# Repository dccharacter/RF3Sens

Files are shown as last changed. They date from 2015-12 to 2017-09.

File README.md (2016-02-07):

<pre>
//###########################################################################################
// RF3Sens (RoboForum triangulation range sensor)
// http://roboforum.ru/forum107/topic15929.html (official language for this forum - russian)
// MIT License
// 2015-2016
// Дмитрий Лилик (aka Dmitry__ @ RoboForum.ru)
// Андрей Пожогин (aka dccharacter  @ RoboForum.ru)
// Сергей Тараненко (aka setar @ RoboForum.ru)
//###########################################################################################
</pre>

Высокоточный (0.01+ mm) оптический барьерный датчик расстояния до поверхности стола 3D принтеров.
Основан на анализе картины засветки пзс матрицы (от мыши) рассеяным излучением от лазерного источника,
по принципу треугольника, при заранее известных углах установки лазера и матрицы.
Не зависит от типа материала стола (теоретически, методика пока в разработке).

Заявленная точность уже получена практическим путем на прототипах.
<pre>
vvv======== печатная каретка 3D принтера ==============vvv
  -- сенсор ------- лазер --(печатная плата сенсора)
         \\\\       ||||
            \         |
             \        |
              \       |
               \      |
                \     |
                 \    |
                  \   |
                   \  |
                    \ |
                     \|
------ уровень -------*--- срабатывания -------------------
                      |\
                      | \
    тут датчик не видит пятна лазера и нет срабатывания
^^^=============== стол 3D принтера ====================^^^
</pre>

* Схемы подключения разных ардуин (и других микроконтроллеров) в папке doc

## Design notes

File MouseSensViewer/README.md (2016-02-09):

Просмотрщик данных с пзс матриц мышек и визуализация картинки на комьютере.
Для:
RoboForum triangulation range sensor
http://roboforum.ru/forum107/topic15929.html (official language for this forum - russian)

##Сборка под Linux

'''
mkdir /home/user-name/tmp/MouseViewer
cd  /home/user-name/tmp/MouseViewer
qmake /path/to/RF3Sens/MouseSensViewer/Viewer.pro
make
'''

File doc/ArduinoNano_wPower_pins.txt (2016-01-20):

режим питания сенсора и лазера с ног микроконтроллера (подаем питание на нужные ноги)

--- сенсор ADNS-2610 --- 
OSC_IN (1 pin)        : на кварц 24MHz
OSC_OUT (2 pin)       : на кварц 24MHz
MOSI(3 pin)           : PB5 D13
SCK (4 pin)           : PB2 D10
GND (6 pin)           : PB4 D12
VDD (7 pin)           : PB3 D11
REFA (8 pin)          : через конденсатор 2.2МКФ на землю (6 pin)

--- лазерный диод 5mW ---
Laser VCC             : PD2 D2
Laser GND             : через сопротивление 100Ом на землю 

--- выход ---
MCU POWER (sensor +5V): VCC
MCU GND (sensor GND)  : GND
led (sensor signal)   : PC5 A5

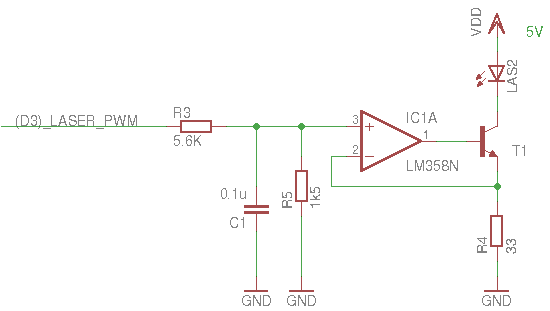
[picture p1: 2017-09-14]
doc/OpAmp-const-current-source.png

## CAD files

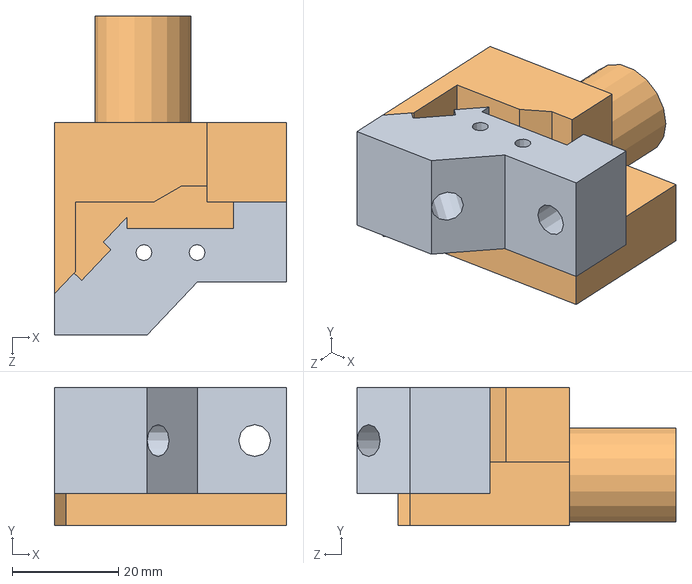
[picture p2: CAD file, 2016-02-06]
Models/universal_to_tube18mm.SLDASM
43.7 x 26.0 x 60.0 mm
Digispark_universal
universal_to_tube18mm

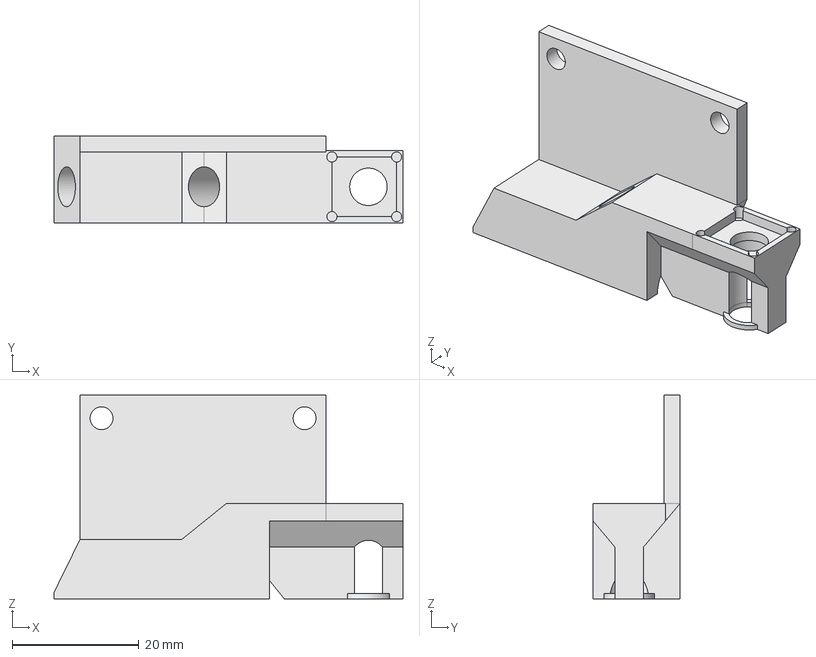
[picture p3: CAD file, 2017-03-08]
Models/Double_laser.FCStd
55.0 x 13.7 x 32.1 mm

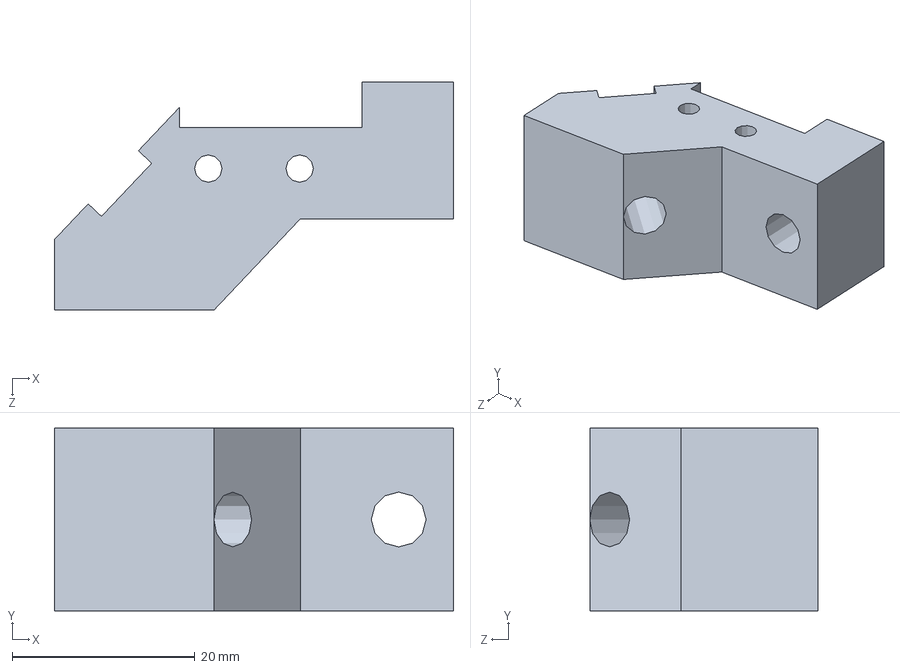
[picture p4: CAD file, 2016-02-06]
Models/Digispark_universal.SLDPRT
43.7 x 20.0 x 25.0 mm

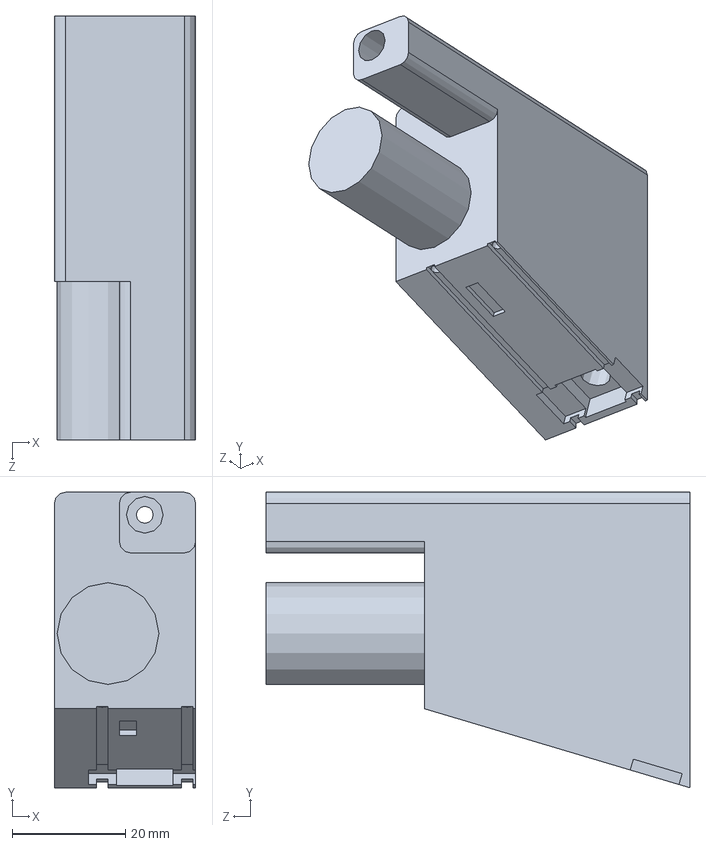
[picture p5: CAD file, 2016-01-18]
Models/ArduinoNano_wPower_tube18mm.SLDPRT
25.0 x 52.3 x 75.0 mm

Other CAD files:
Models/ArduinoNano_wPower_tube18mm.STL
Models/Double_laser.stl
Models/universal_to_tube18mm.SLDPRT
Models/universal_to_tube18mm.STL

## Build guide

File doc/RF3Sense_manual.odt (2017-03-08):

Синхронизация с электроникой принтера через g-code (trigger pin)

ссылка: http://roboforum.ru/post343825.html?hilit=trigger#p343825

G1 F2000 Z5 ;travel to initial position (absolute) <- здесь z устанавливаешь равным полному ходу датчика
G4 S1 ;sleep for 1 sec
M42 P4 S255 ;set trigger pin 4 HIGH (servo 4 signal pin)
G1 F60 Z0 ;travel to end position slowly
M400 ;wait for previous command to complete
M42 P4 S0 ;set trigger pin LOW

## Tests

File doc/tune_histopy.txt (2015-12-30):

Sketch uses 1 268 bytes (4%) of program storage space. Maximum is 30 720 bytes.
Global variables use 236 bytes (11%) of dynamic memory, leaving 1 812 bytes for local variables. Maximum is 2 048 bytes.

программный spi
Sketch uses 912 bytes (2%) of program storage space. Maximum is 30 720 bytes.
Global variables use 235 bytes (11%) of dynamic memory, leaving 1 813 bytes for local variables. Maximum is 2 048 bytes.

SoftSerial
Sketch uses 3 012 bytes (50%) of program storage space. Maximum is 6 012 bytes.
Global variables use 129 bytes of dynamic memory.
замена SoftSerial на SendOnlySoftwareSerial
Sketch uses 1 878 bytes (31%) of program storage space. Maximum is 6 012 bytes.
Global variables use 42 bytes of dynamic memory.

Sketch uses 4 468 bytes (14%) of program storage space. Maximum is 30 720 bytes.
Global variables use 254 bytes (12%) of dynamic memory, leaving 1 794 bytes for local variables. Maximum is 2 048 bytes.
без Serial.println(String(Frame...
Sketch uses 2 866 bytes (9%) of program storage space. Maximum is 30 720 bytes.
Global variables use 247 bytes (12%) of dynamic memory, leaving 1 801 bytes for local variables. Maximum is 2 048 bytes.

Выпилил ненужный:
Frame[(ARRAY_WIDTH * ARRAY_HEIGHT)+1] = 0xff;  // frame data is 0..63 or 0..127 so delimiter 255 is safe

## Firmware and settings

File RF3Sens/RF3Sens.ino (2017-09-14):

//###########################################################################################
// RF3Sens (RoboForum triangulation range sensor)
// http://roboforum.ru/forum107/topic15929.html (official language for this forum - russian)
// MIT License
// 2015-2016
// Дмитрий Лилик (aka Dmitry__ @ RoboForum.ru)
// Андрей Пожогин (aka dccharacter  @ RoboForum.ru)
// Сергей Тараненко (aka setar @ RoboForum.ru)
//###########################################################################################

#include "Config.h"
#if defined(DEBUG_TYPE) && defined(SOFTWARE_SERIAL)
  #include <SendOnlySoftwareSerial.h>
#endif //#if defined(DEBUG_TYPE) && defined(SOFTWARE_SERIAL)

byte ADNS_read(uint8_t address);
void ADNS_reset(void);
void ADNS_write(uint8_t addr, uint8_t data);
inline void params_grab(uint8_t *buffer, uint8_t ifReset);
inline void pixel_grab(uint8_t *buffer, uint16_t nBytes); 
inline void pixel_and_params_grab(uint8_t *buffer);
inline uint8_t single_line_grab(uint8_t *buffer);
void RefrPowerLaser(uint16_t power, uint16_t value, uint16_t halfDev);
void ByteToString(uint8_t a);
void Uint16ToString(uint16_t a);

unsigned char Str[5];
int16_t RegPowLaser = 0;

void setup(){
  pinMode(3, OUTPUT);
  TCCR2A = 0;
  TCCR2B = 0;
  TCCR2A = _BV(COM2B1) | _BV(WGM21) | _BV(WGM20);
  TCCR2B = _BV(CS20); // no prescaler
  OCR2B = 50;

  pinMode(A5, INPUT);

  //set pin I/O direction
#if defined(USE_NCS)
  PIN_OUTPUT(NCS);
  PIN_HIGH(NCS);
#endif //USE_NCS
  PIN_OUTPUT(LED);
  PIN_HIGH(LED);
#if defined(DEBUG_TYPE) && defined(TRIG_PIN)
  PIN_INPUT(TRIG);
#endif //defined(DEBUG_TYPE) && defined(TRIG_PIN)


  PIN_OUTPUT(laser1_vcc);
  PIN_OUTPUT(laser2_vcc);
  PIN_OUTPUT(laser_pwm);
  analogWrite(9, 0); //preset all analogWrite values so I can just later change OCR1A

//initialize SPI
  PIN_OUTPUT(NCLOCK);
  PIN_HIGH(NCLOCK);
  PIN_OUTPUT(SDIO);
  PIN_LOW(SDIO);

//#if defined(DEBUG_TYPE)
  SERIAL_OUT.begin(SERIAL_SPEED);
//#endif // defined(DEBUG_TYPE)

  delay(1000);
  ADNS_reset();
}

void loop(){
//###########################################################################################
// штатный режим датчика для 3D принтера
#ifndef DEBUG_TYPE
  uint8_t Frame[NUM_PIXS + 7] = {0};
  uint8_t dataSum, dataSqual, lineMax;
  
  PIN_LOW(LED);

  PIN_LOW(laser1_vcc); //enable base laser
  analogWrite(9,130);

  while(1){
    params_grab(Frame, 1);
    dataSum = Frame[3];
    dataSqual = Frame[0];
    ByteToString(RegPowLaser); SERIAL_OUT.write(Str[2]); SERIAL_OUT.write(Str[1]);
      SERIAL_OUT.write(Str[0]); SERIAL_OUT.write(0x09);
    ByteToString(dataSum); SERIAL_OUT.write(Str[2]); SERIAL_OUT.write(Str[1]);
      SERIAL_OUT.write(Str[0]); SERIAL_OUT.write(0x09);
    if (dataSqual > 30) {
      lineMax = single_line_grab(Frame);
      ByteToString(lineMax); SERIAL_OUT.write('.'); SERIAL_OUT.write(Str[2]); SERIAL_OUT.write(Str[1]);
        SERIAL_OUT.write(Str[0]); SERIAL_OUT.write(0x0a);
      if (lineMax > 60) {
          PIN_HIGH(LED);
          delay(100);
      }
    }
    RefrPowerLaser(dataSum, 23, 2);
    SERIAL_OUT.write(0x0a);
    
    PIN_LOW(LED);
  }
//###########################################################################################
// отладочные режимы
#else //ifndef DEBUG_TYPE
//-------------------------------------------------------------------------------------------
#if DEBUG_TYPE ==1
//-------------------------------------------------------------------------------------------
  byte Frame[NUM_PIXS + 7] = {0}, dataMax, lineMax;
  byte dataMin, lineMin;
  //uint8_t laserId = 2; // 0 = off; 1 = laser 1; 2 = laser 2; 
  //uint16_t dataShutt;
  
  PIN_LOW(LED);

  PIN_LOW(laser1_vcc); //enable base laser
  PIN_HIGH(laser2_vcc); //disable matrix laser
  analogWrite(9,130);

  while(1){
    //pixel_and_params_grab(Frame);
    //dataMax = Frame[NUM_PIXS + 1];
    //lineMax = Frame[NUM_PIXS + 0];
    //lineMin = Frame[NUM_PIXS + 3];

    //RegPowLaser = (uint8_t)(analogRead(A5) >> 2);    
    //OCR2B = RegPowLaser;
    OCR2B += 1;
   //   }
     /* if (lineMax > 22) { //bingo!
        PIN_HIGH(LED);
        delay(200);
      } else {
        PIN_LOW(LED);
      }*/
    delay(1);
    //} else {
    //  PIN_LOW(LED);
    //}
    
    //SERIAL_OUT.write(Frame, NUM_PIXS + 7); delay(2);// send frame in raw format
  }
//-------------------------------------------------------------------------------------------
#elif DEBUG_TYPE ==2
//-------------------------------------------------------------------------------------------
  byte Frame[NUM_PIXS + 7];

  byte data;
  while(1){
    //data = ADNS_read(ADNS_SQUAL);
    data = ADNS_read(ADNS_MAX_PIX);
    //data = ADNS_read(ADNS_PIX_SUM);

    if(data > ADNS_CONST_MAX){
      PIN_LOW(LED);
    }
    else{
      PIN_HIGH(LED);
      pixel_and_params_grab(Frame);
      SERIAL_OUT.write(Frame, NUM_PIXS+7); // send frame in raw format
    }
  }
//-------------------------------------------------------------------------------------------
#elif DEBUG_TYPE ==3
//-------------------------------------------------------------------------------------------
  //листинг для электронных таблиц: В шапке названия, дальше только данные разделенные "tab".
  byte Frame[7];
  uint8_t dataMax, lineMax, dataSum;
  //заголовок
  SERIAL_OUT.println  (F  ("Squal:\tMax:\tMin:\tSum:\tShutter:\tLaserPower:"));
  while(1){
//        RegPowLaser = OCR2B;    
//	OCR2B += 1;
//    params_grab(Frame);

    single_line_grab(Frame);
    dataMax = Frame[NUM_PIXS + 1];
    //dataMin = Frame[NUM_PIXS + 2];
    lineMax = Frame[NUM_PIXS + 0];
    dataSum = Frame[NUM_PIXS + 3];

    //if (dataMax - dataMin > 30) { //laser spot is visible, arm the sensor
    //  if (!(dataMax - dataMin > 40 && lineMax - lineMin > 7)) { //spot has not reached the last line
        //dataShutt = ((*(Frame + NUM_PIXS + 4)) << 8) + *(Frame + NUM_PIXS + 5);
    RefrPowerLaser(dataSum, 35, 2);
    //   }
    if (lineMax > 60) { //22 - bingo!
      PIN_HIGH(LED);
      delay(100);
    } else {
      PIN_LOW(LED);
}
    ByteToString(Frame[NUM_PIXS + 0]); SERIAL_OUT.write(Str[2]); SERIAL_OUT.write(Str[1]); SERIAL_OUT.write(Str[0]); SERIAL_OUT.write(0x09);
    ByteToString(Frame[NUM_PIXS + 1]); SERIAL_OUT.write(Str[2]); SERIAL_OUT.write(Str[1]); SERIAL_OUT.write(Str[0]); SERIAL_OUT.write(0x09);
    //ByteToString(Frame[2]); SERIAL_OUT.write(Str[2]); SERIAL_OUT.write(Str[1]); SERIAL_OUT.write(Str[0]); SERIAL_OUT.write(0x09);
    ByteToString(Frame[NUM_PIXS + 3]); SERIAL_OUT.write(Str[2]); SERIAL_OUT.write(Str[1]); SERIAL_OUT.write(Str[0]); SERIAL_OUT.write(0x09);
    Uint16ToString(Frame[NUM_PIXS + 4] *256 + Frame[NUM_PIXS + 5]);
    SERIAL_OUT.write(Str[4]);
    SERIAL_OUT.write(Str[3]);
    SERIAL_OUT.write(Str[2]);
    SERIAL_OUT.write(Str[1]);
    SERIAL_OUT.write(Str[0]);
    SERIAL_OUT.write(0x09);
    ByteToString(Frame[NUM_PIXS + 6]); SERIAL_OUT.write(Str[2]); SERIAL_OUT.write(Str[1]); SERIAL_OUT.write(Str[0]); SERIAL_OUT.write(0x09);
    SERIAL_OUT.write(0x0d);
    SERIAL_OUT.write(0x0a);

#if SERIAL_SPEED > 115200
      delay(20);
#else
      delay(60);  //задержка больше из-за низкой скорости Serial
#endif
  }
//-------------------------------------------------------------------------------------------
#elif DEBUG_TYPE ==4
//-------------------------------------------------------------------------------------------
  //Как 3-й режим, но по разрешению сигнала pin_TRIG
  byte Frame[7];
  PIN_OUTPUT(gpio1);
  PIN_LOW(gpio1);

  PIN_LOW(laser1_vcc); //enable base laser
  PIN_HIGH(laser2_vcc); //disable matrix laser
  RegPowLaser = 140;
  analogWrite(9, RegPowLaser);

  // начинаем с печати шапки
  SERIAL_OUT.println (F  ("Squal:\tMax:\tMin:\tSum:\tShutter:\tLaserPower:"));

  while(1){

    if(PIN_READ(TRIG)){ // каждое измерение начинается с сигнала триггера (взводится в g-коде)
      
      while(PIN_READ(TRIG));

      params_grab(Frame);

      ByteToString(Frame[0]); SERIAL_OUT.write(Str[2]); SERIAL_OUT.write(Str[1]); SERIAL_OUT.write(Str[0]); SERIAL_OUT.write(0x09);
      ByteToString(Frame[1]); SERIAL_OUT.write(Str[2]); SERIAL_OUT.write(Str[1]); SERIAL_OUT.write(Str[0]); SERIAL_OUT.write(0x09);
      ByteToString(Frame[2]); SERIAL_OUT.write(Str[2]); SERIAL_OUT.write(Str[1]); SERIAL_OUT.write(Str[0]); SERIAL_OUT.write(0x09);
      ByteToString(Frame[3]); SERIAL_OUT.write(Str[2]); SERIAL_OUT.write(Str[1]); SERIAL_OUT.write(Str[0]); SERIAL_OUT.write(0x09);
      Uint16ToString(Frame[4] *256 + Frame[5]);
      SERIAL_OUT.write(Str[4]);
      SERIAL_OUT.write(Str[3]);
      SERIAL_OUT.write(Str[2]);
      SERIAL_OUT.write(Str[1]);
      SERIAL_OUT.write(Str[0]);
      SERIAL_OUT.write(0x09);
      ByteToString(Frame[6]); SERIAL_OUT.write(Str[2]); SERIAL_OUT.write(Str[1]); SERIAL_OUT.write(Str[0]); SERIAL_OUT.write(0x09);
      SERIAL_OUT.write(0x0a);
      SERIAL_OUT.write(0x0d);

#if SERIAL_SPEED > 115200
      delay(20);
#else
      delay(60);  //задержка больше из-за низкой скорости Serial
#endif

    // после того, как считали значения и отправили их в сериал, даем марлину
    // сигнал о готовности к следующему шагу
    PIN_HIGH(gpio1);
    delay(40);
    PIN_LOW(gpio1);
    }
  }
//-------------------------------------------------------------------------------------------
#elif DEBUG_TYPE ==5
//-------------------------------------------------------------------------------------------
  while(1){
    unsigned int motion = 0;
    //check for movement
    motion = ADNS_read(ADNS_MOTION);
    if (motion > 127){
      //there has been a motion! Print the x and y movements
      SERIAL_OUT.println("X:" + String(ADNS_read(ADNS_DELTA_X)) + " Y:" + String(ADNS_read(ADNS_DELTA_Y)));
    }
  }
//-------------------------------------------------------------------------------------------
#elif DEBUG_TYPE ==6
//-------------------------------------------------------------------------------------------
  uint8_t Frame[7];
  uint8_t laserId = 2; // 0 = off; 1 = laser 1; 2 = laser 2; 
  //заголовок

  SERIAL_OUT.println  (F  ("Squal:\tMax:\tMin:\tSum:\tShutter:\tLaserId:"));
  while(1){
    params_grab(Frame);

  if (laserId == 2) {
	  PIN_HIGH(laser1_vcc);
	  PIN_LOW(laser2_vcc);
	  laserId = 1;
  } else {
	  PIN_HIGH(laser2_vcc);
	  PIN_LOW(laser1_vcc);
	  laserId = 2;
  }
    ByteToString(Frame[0]); SERIAL_OUT.write(Str[2]); SERIAL_OUT.write(Str[1]); SERIAL_OUT.write(Str[0]); SERIAL_OUT.write(0x09);
    ByteToString(Frame[1]); SERIAL_OUT.write(Str[2]); SERIAL_OUT.write(Str[1]); SERIAL_OUT.write(Str[0]); SERIAL_OUT.write(0x09);
    ByteToString(Frame[2]); SERIAL_OUT.write(Str[2]); SERIAL_OUT.write(Str[1]); SERIAL_OUT.write(Str[0]); SERIAL_OUT.write(0x09);
    ByteToString(Frame[3]); SERIAL_OUT.write(Str[2]); SERIAL_OUT.write(Str[1]); SERIAL_OUT.write(Str[0]); SERIAL_OUT.write(0x09);
    Uint16ToString(Frame[4] *256 + Frame[5]);
    SERIAL_OUT.write(Str[4]);
    SERIAL_OUT.write(Str[3]);
    SERIAL_OUT.write(Str[2]);
    SERIAL_OUT.write(Str[1]);
    SERIAL_OUT.write(Str[0]);
    SERIAL_OUT.write(0x09);
    ByteToString(laserId); SERIAL_OUT.write(Str[2]); SERIAL_OUT.write(Str[1]); SERIAL_OUT.write(Str[0]); SERIAL_OUT.write(0x09);
    SERIAL_OUT.write(0x0d);
    SERIAL_OUT.write(0x0a);

#if SERIAL_SPEED > 115200
      delay(20);
#else
      delay(60);  //задержка больше из-за низкой скорости Serial
#endif //SERIAL_SPEED > 115200
  }
#endif //DEBUG_TYPE
#endif // #else #ifndef DEBUG_TYPE
}

//###########################################################################################
// процедуры
//-------------------------------------------------------------------------------------------
void RefrPowerLaser(uint16_t power, uint16_t target_value, uint16_t halfDeviation)
{
  //if (abs((int16_t)target_value - (int16_t)power) > halfDeviation) {
    if (power < target_value) {
      RegPowLaser++;
    } else if (power > target_value) {
      RegPowLaser--;
    }
    if (RegPowLaser > 255) {
      RegPowLaser = 255;
    } else if (RegPowLaser < 0) {
      RegPowLaser = 0;
    }
    OCR2B = (uint8_t)RegPowLaser;
  //}
}
//-------------------------------------------------------------------------------------------
void ADNS_reset(void){
#ifdef sens_type_ADNS_5020
  ADNS_write(0x3a,0x5a);
  delay(1000);
  ADNS_write(0x0d, 0x01);  // Set 1000cpi resolution
  delay(1000);
#endif
#if  defined(sens_type_ADNS_2610) || defined(sens_type_ADNS_2620)
  ADNS_write(ADNS_CONF,0x80);
  delay(1000);
  ADNS_write(ADNS_CONF,0x01); //Always awake
  delay(2);
  ADNS_write(ADNS_FRAME_PERIOD, 0xC2); //set framerate to 3000fps
  delay(2);
#endif
}

//-------------------------------------------------------------------------------------------
void ADNS_write(byte address, byte data){
  #if defined(USE_NCS)
    PIN_LOW(NCS);
  #endif
  // send in the address and value via SPI:
  address |= 0x80;  //признак записи адреса
  for (byte i = 0x80; i; i >>= 1){
    PIN_LOW(NCLOCK);
    address & i ? PIN_HIGH(SDIO) : PIN_LOW(SDIO);
    asm volatile ("nop");
    PIN_HIGH(NCLOCK);
  }

  //delayMicroseconds(1);

  for (byte i = 0x80; i; i >>= 1){
    PIN_LOW(NCLOCK);
    data & i ? PIN_HIGH(SDIO) : PIN_LOW(SDIO);
    asm volatile ("nop");
    PIN_HIGH(NCLOCK);
  }
  //t SWW. SPI Time between Write Commands
  delayMicroseconds(ADNS_DELAY_TSWW);

  #if defined(USE_NCS)
    PIN_HIGH(NCS);
  #endif
}

//-------------------------------------------------------------------------------------------
byte ADNS_read(byte address){
  #if defined(USE_NCS)
    PIN_LOW(NCS);
  #endif

  address &= ~0x80;  //признак записи данных
  for (byte i = 0x80; i; i >>= 1){
    PIN_LOW(NCLOCK);
    address & i ? PIN_HIGH(SDIO) : PIN_LOW(SDIO);
    asm volatile ("nop");
    PIN_HIGH(NCLOCK);
  }

  // prepare io pin for reading
  PIN_INPUT(SDIO);

  // t SRAD. SPI Read Address-Data Delay
  delayMicroseconds(ADNS_DELAY_TSRAD);

  // read the data
  byte data = 0;
  for (byte i = 8; i; i--){
    // tick, tock, read
    PIN_LOW(NCLOCK);
    asm volatile ("nop");
    PIN_HIGH(NCLOCK);
    data <<= 1;
    if (PIN_READ(SDIO)) data |= 0x01;
  }

  #if defined(USE_NCS)
    PIN_HIGH(NCS);
  #endif
  PIN_OUTPUT(SDIO);
  // t SRW & t SRR = 1μs.
  delayMicroseconds(2);
  return data;
}
//-------------------------------------------------------------------------------------------
inline uint8_t single_line_grab(uint8_t *buffer) {

  uint8_t temp_byte;
  //uint16_t nBytes = NUM_PIXS; //18;
  uint16_t nBytes = 18;
  uint8_t linePix = 18;
  uint8_t lineMax = 0;
  //uint8_t lineMin = 255; //determine max and min pix in data read

  //reset the pixel grab counter
  ADNS_write(ADNS_PIX_GRAB, 0x00);

  for (uint16_t count = 0; count < nBytes; count++) {
    while (1) {
      temp_byte = ADNS_read(ADNS_PIX_GRAB);
      if (temp_byte & ADNS_PIX_DATA_VALID) {
        break;
      }
    }
    temp_byte &= ADNS_MASK_PIX;
    *(buffer + count) = temp_byte;  // only n bits are used for data
    if (temp_byte > lineMax) {
      lineMax = temp_byte;
    }
    //if (temp_byte < lineMin) {
    //  lineMin = temp_byte;
    //}
  }

  return lineMax;
}
//-------------------------------------------------------------------------------------------
inline void pixel_grab(uint8_t *buffer, uint16_t nBytes) {
  uint8_t temp_byte;

  //reset the pixel grab counter
  ADNS_write(ADNS_PIX_GRAB, 0x00);

  for (uint16_t count = 0; count < nBytes; count++) {
    while (1) {
      temp_byte = ADNS_read(ADNS_PIX_GRAB);
      if (temp_byte & ADNS_PIX_DATA_VALID) {
        break;
      }
    }
    *(buffer + count) = temp_byte & ADNS_MASK_PIX;  // only n bits are used for data
  }
}
//-------------------------------------------------------------------------------------------
inline void params_grab(uint8_t *buffer, uint8_t ifReset) {
  if (ifReset) {
    uint8_t temp_byte;
    ADNS_write(ADNS_PIX_GRAB, 0x00);
    while (1) {
      temp_byte = ADNS_read(ADNS_PIX_GRAB);
      if (temp_byte & ADNS_PIX_DATA_VALID) {
        break;
      }
    }
  }
  *(buffer + 0) = ADNS_read(ADNS_SQUAL);
  *(buffer + 1) = ADNS_read(ADNS_MAX_PIX);
  *(buffer + 2) = ADNS_read(ADNS_MIN_PIX);
  *(buffer + 3) = ADNS_read(ADNS_PIX_SUM);
  *(buffer + 4) = ADNS_read(ADNS_SHUTTER_UPPER);
  *(buffer + 5) = ADNS_read(ADNS_SHUTTER_LOWER);
  *(buffer + 6) = (uint8_t)RegPowLaser;
}
//-------------------------------------------------------------------------------------------
inline void pixel_and_params_grab(uint8_t *buffer) {
	pixel_grab(buffer, NUM_PIXS);
	params_grab(buffer + NUM_PIXS, 0);
}
//-------------------------------------------------------------------------------------------
void ByteToString(uint8_t a){
  Str[0] = '0';
  Str[1] = '0';
  Str[2] = '0';
  if (!a) return;
  Str[0] = a % 10 + '0'; a /= 10;
  if (!a) return;
  Str[1] = a % 10 + '0'; a /= 10;
  if (!a) return;
  Str[2] = a % 10 + '0';
}
//-------------------------------------------------------------------------------------------
void Uint16ToString(uint16_t a){
  Str[0] = '0';
  Str[1] = '0';
  Str[2] = '0';
  Str[3] = '0';
  Str[4] = '0';
  if (!a) return;
  Str[0] = a % 10 + '0'; a /= 10;
  if (!a) return;
  Str[1] = a % 10 + '0'; a /= 10;
  if (!a) return;
  Str[2] = a % 10 + '0'; a /= 10;
  if (!a) return;
  Str[3] = a % 10 + '0'; a /= 10;
  if (!a) return;
  Str[4] = a % 10 + '0';
}
//-------------------------------------------------------------------------------------------
uint8_t ByteToAscii_h(uint8_t x){
  uint8_t tmpByte;

  tmpByte = (x >> 4) + 0x30;
  if (tmpByte > 0x39) { tmpByte += 0x07; }
  return tmpByte;
}
//-------------------------------------------------------------------------------------------
uint8_t ByteToAscii_l(uint8_t x){
  uint8_t tmpByte;
  tmpByte = (x & 0x0f) + 0x30;
  if (tmpByte > 0x39) { tmpByte += 0x07; }
  return tmpByte;
}

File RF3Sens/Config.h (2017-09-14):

//###########################################################################################
// RF3Sens (RoboForum triangulation range sensor)
// http://roboforum.ru/forum107/topic15929.html (official language for this forum - russian)
// MIT License
// 2015-2016
// Дмитрий Лилик (aka Dmitry__ @ RoboForum.ru)
// Андрей Пожогин (aka dccharacter  @ RoboForum.ru)
// Сергей Тараненко (aka setar @ RoboForum.ru)
//###########################################################################################

/* Config.h */
//###########################################################################################
//        Ручные настройки
//###########################################################################################
/*
При отсутствии флага DEBUG_TYPE, программа быстро обрабатывает соотв. регистр и выдает данные на led (штатная работа принтера).
При установленном флаге DEBUG_TYPE, по serial port передаются данные:
DEBUG_TYPE = 1  Передача картинки для фокусировки обьектива, колич. байт = ARRAY_WIDTH * ARRAY_HEIGHT
DEBUG_TYPE = 2  Для теста точности позиционирования (идея dccharacter-а). 
                Поиск порога как в штатном режиме (важна скорость), как только сработает порог - выдача картинки в serial port
DEBUG_TYPE = 3  Передача в текстовом виде на терминал данных: Max_Pix, Min_Pix, Pix_Sum, Shutter
DEBUG_TYPE = 4  Как 3-й режим, но по разрешению сигнала pin_TRIG (лог точно ограничен сигналом z_probe)
DEBUG_TYPE = 5  Данные перемещения мышки.
DEBUG_TYPE = 6 Тестирование режима двойного лазера
*/
#define DEBUG_TYPE 1 
#define NUM_SAMPLES_PER_MEASURE 5 //количество данных для 4-го режима

/*
Актуально только если есть флаг DEBUG_TYPE
Если определено то применяется программный Serial порт (только одна нога для передачи данных)
Для платы Digispark это единственный вариант и автоматически включается на 1 ногу
Если не определено, для дебага используется Hardware Serial
*/
//#define SOFTWARE_SERIAL 1 // одновременно и признак софтового serial и номер ноги для передачи данных (TX PIN)
#define SERIAL_SPEED 230400

/*
Тип сенсора, выбрать один нужный
*/
//#define SENS_TYPE_ADNS_5020
//#define SENS_TYPE_ADNS_2610
#define SENS_TYPE_ADNS_2620

/*
Используем ли питание с контроллера
*/
//#define laser_power_via_mcu // режим питания лазера с ног микроконтроллера (подаем питание на нужные ноги)
//#define sens_power_via_mcu // режим питания сенсора с ног микроконтроллера (подаем питание на нужные ноги)

/*
Тип контроллера, выбрать один нужный
*/
//#define DIGI_SPARK
//#define ARDUINO_NANO // базовая распайка arduino nano
//#define ARDUINO_NANO_wPOWER  // распайка сенсора на arduino nano для питания с ног микроконтроллера
#define ARDUINO_NANO_DOUBLE_LASER

/*
Алгоритм детектирования, выбрать один нужный
*/
//#define Algo_MaxPix         // простейший режим - срабатывание когда в поле зрения начинает появляться краешек пятна лазера.
                            // самый стабильный, но дистанция срабатывания разная при разном цвете поверхности
//#define Algo_MaxSqualMA   // режим обнаружения максимума Squal, т.к. параметр не стабилен введено сглаживание и анализ через среднескользящие
                            // экспериментальный

//###########################################################################################
//        Конец ручных настроек
//###########################################################################################


#if (defined(DIGI_SPARK) && !defined(SOFTWARE_SERIAL)) 
  #error "This board can be used only with SOFTWARE_SERIAL"
#endif

#if DEBUG_TYPE == 5
  #if defined(SENS_TYPE_ADNS_2610) || defined(SENS_TYPE_ADNS_2620)
    #error "This sensor doesn't have a motion register; DEBUG_TYPE 5 is unavailable"
  #endif
#endif


//###########################################################################################
//        Подключение библиотек 
//###########################################################################################
#if defined(SENS_TYPE_ADNS_5020)
  #include "sens/ADNS_5020.h"
#endif
#if defined(SENS_TYPE_ADNS_2610)
  #include "sens/ADNS_2610.h"
#endif
#if defined(SENS_TYPE_ADNS_2620)
  #include "sens/ADNS_2620.h"
#endif

#if defined(DIGI_SPARK)
#include "boards/Digispark.h"
#endif
#if defined(ARDUINO_NANO)
#include "boards/ArduinoNano.h"
#endif
#if defined(ARDUINON_NANO_wPOWER)
#include "boards/ArduinoNano.h"
#endif
#if defined(ARDUINO_NANO_DOUBLE_LASER)
#include "board_ArduinoNano_doubleLaser.h"
#endif

#if defined(DEBUG_TYPE) && defined(SOFTWARE_SERIAL)
  #include <SendOnlySoftwareSerial.h>
  SendOnlySoftwareSerial MyDbgSerial(SOFTWARE_SERIAL, false); //true allows to connect to a regular RS232 without RS232 line driver
  #define SERIAL_OUT MyDbgSerial
#else
  #define SERIAL_OUT Serial
#endif
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

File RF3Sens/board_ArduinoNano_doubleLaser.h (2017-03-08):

//###########################################################################################
// RF3Sens (RoboForum triangulation range sensor)
// http://roboforum.ru/forum107/topic15929.html (official language for this forum - russian)
// MIT License
// 2015-2016
// Дмитрий Лилик (aka Dmitry__ @ RoboForum.ru)
// Андрей Пожогин (aka dccharacter  @ RoboForum.ru)
// Сергей Тараненко (aka setar @ RoboForum.ru)
//###########################################################################################

/* board_ArduinoNano.h */

#if defined(use_nCS)
  //pin_nCS  PB2 SS D10
  #define NCS_PIN        2
  #define NCS_DDR        DDRB
  #define NCS_PORT       PORTB
#endif 

//pin_led
//PB5 D13
#define LED_PIN         5
#define LED_DDR         DDRB
#define LED_PORT        PORTB

//pin_nClock (SCK)
//PB4 D12
#define NCLOCK_PIN      4
#define NCLOCK_DDR      DDRB
#define NCLOCK_PORT     PORTB

//MOSI
//PB3  D11
#define SDIO_PIN        3
#define SDIO_DDR        DDRB
#define SDIO_PORT       PORTB
#define SDIO_IN    PINB

//PD4 TRIGGER_PIN
//PD4 D4
#define TRIG_PIN        4
#define TRIG_DDR        DDRD
#define TRIG_IN    PIND

//Laser 1 VCC
//PD5 D5
#define laser1_vcc_PIN   5
#define laser1_vcc_DDR   DDRD
#define laser1_vcc_PORT  PORTD

//Laser 2 VCC
//PD6 D6
#define laser2_vcc_PIN   6
#define laser2_vcc_DDR   DDRD
#define laser2_vcc_PORT  PORTD

//Laser PWM control
//PB1 D9
#define laser_pwm_PIN	1
#define laser_pwm_DDR	DDRB
#define laser_pwm_PORT	PORTB

// GPIO for signalling to external board
// PRD7 D7
#define gpio1_PIN	7
#define gpio1_DDR	DDRD
#define gpio1_PORT	PORTD

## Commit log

2015-12-30 Начальный коммит На базе разработки из этой темы http://roboforum.ru/forum107/topic15929.html
2016-01-01 Исправил ошибки: 1) В функции ADNS_reset(void) были неправильные дефайны и не определен датчик 2620 2) Изменил структуру включения файлов контроллеров через дефайны - теперь компилируется под все тип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
    [Config.h, RF3Sens.ino]
2016-01-08 переименование board_ArduinoNano_mcupower.h -> board_ArduinoNano_wPower.h перемещение tune_histopy.txt -> doc/tune_histopy.txt
2016-01-08 Добавлено описание проекта
    [digispark_adns2620.sch]
2016-01-08 Учет задержки от скорости порта при дебаге
2016-01-08 Добавлен визуализатор пзс матрицы на компьютере, для калибровки датчика
2016-01-09 Fixed bug with incorrect ADNS_reset function for ADNS 2610 and ADNS 2620 sensors. Now sensors don't go to power saving mode/sleep
    [RF3Sens.ino]
2016-01-18 Документация ADNS-2610
2016-01-18 Модель корпуса сенсора на базе ArduinoNano c креплением вместо тубы 18мм
    [ArduinoNano_wPower_tube18mm.SLDPRT, ArduinoNano_wPower_tube18mm.STL]
2016-01-20 Описание подключения ADNS-2610 на Arduino Nano
2016-02-06 Переход на более компактные define и добавлена регулировка мощности лазера через FastPWM
2016-02-06 модель корпуса для контроллера digispark с универсальным сменным типом крепления (SolidWorks2014)
    [Digispark_universal.SLDPRT, universal_to_tube18mm.SLDASM, universal_to_tube18mm.SLDPRT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]
2016-02-06 Добавлена схема подключения лазера в режиме управления мощностью по FastPWM
    [digispark_adns2620.sch]
2016-02-06 исправил ошибку в текстовом выводе дебаг режимов 3,4
    [RF3Sens.ino]
2016-02-07 Улучшение алгоритма детекта поверхности
2016-02-09 Added functions declarations (prototypes); Added check for debug_type incompatibility with some sensors.\r\n\r\nFunction prototypes are not automatically added by Arduino-Makefile, so I included them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
    [Config.h, RF3Sens.ino]
2016-02-09 Fixed error in terminal output (standard requies \r\b, i.e. 0x0D 0x0A). Also fixed a bug in previous commit (sensor/debug check).
    [Config.h, RF3Sens.ino]
2016-02-09 Добавлена обработка ошибки использования DigiSpark без определения software serial
2016-02-09 переименовано определение PIN_IN в PIN_READ
2016-02-09 переименованы констаты, алгоритм улучшен анализом среднескользящими.
2016-02-09 Добавлен выбор алгоритма детекта поверхности
2016-02-09 заголовки базовых плат и датчиков перенесены в boards и sens соответственно
2016-02-09 изменение путей подключения boards и sens
2016-02-09 мелкие правки
2016-02-10 Тестирование мерцающего лазера
2016-02-10 Added board_ArduinoNano-doubeLaser.h to tracking
2016-02-10 Working double laser
    Pin definitions are in board_ArduinoNano_doubleLaser.h
    comment out debug_level in Config.h to enable 3d printer default mode or
    set debug_level 1 to get visual data in MouseViewer.
    The code is just a quick hack and needs to be fully redone
    [Double_laser.FCStd, Double_laser.stl]
2016-05-10 Pre-change commit; will be adding laser PWM and entirely changing the sensor logic
2016-07-24 Testing new 1-line approach KomX
    [LaserPWMresponse_meas.ods]
2016-07-26 working "Dmitry" mode with constant dataMax=50. ToDo: speed up the sensor to see if theres any benefit
2016-07-26 Working measurement; not really working visualization. TODO - fix visualization
    [ADNS_2620.h, RF3Sens.ino]
2016-07-27 Before pushing to github. All the functions are oworking properly, but detection threshold needs to be reverted back to simpla maxPix comparison
    [RF3Sens.ino, dialog.cpp]
2016-07-29 rewrote debug mode 4. Now waits for HIGH on TRIG pin, makes single measurement, writes result to serial and after that signals to Marlin to proceed with gpio1 pin HIGH-LOW sequence. Works perfectly
    [laser_source_opamp.sch]
2017-03-05 Resuming after long pause. Commiting stuff the I don't remember making. Will probably have to review it later
    [Chart.ods, RFSens.sch]
2017-03-08 some cosmetic work done and verified the sensor is working
2017-09-14 Laser power source schematics updated and tested @5V.
    The previous version of schematics doesn't work as intended
    [laser_source_opamp.sch]
